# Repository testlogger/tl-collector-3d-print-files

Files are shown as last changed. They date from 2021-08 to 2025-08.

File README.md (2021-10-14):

# TestLogger Collector 3D printing file library
This repository is used to share STL files for TestLogger Collector components like cases and sensor brackets. As everything is 3D printed in production versions, we want to share the models for the users to be able to print spare parts by themselves and also users can share their own designs for brackets for others to print.

# Contributing
If you like to contribute your models to this library, then you can send models via email to info@testlogger.com or upload it in Discord.

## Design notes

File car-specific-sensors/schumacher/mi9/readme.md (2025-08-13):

# Schumacher Mi9 Brackets

This folder contains all brackets for the **Schumacher Mi9 touring car** and instructions for installation.

---

## 📑 Table of Contents
- [🧲 Magnet Ring](#-magnet-ring)
  - [Before You Start](#before-you-start)
  - [Installing the Magnet Ring](#installing-the-magnet-ring)
  - [Installing the Magnets](#installing-the-magnets)
- [⚙️ Wheel Speed Sensor Bracket](#️-wheel-speed-sensor-bracket)
- [💡 Tips & Notes](#-tips--notes)

---

## 🧲 Magnet Ring

The magnet ring has slots for **4 magnets**. The designed magnet size is **3×1 mm**.

### Before You Start
> ⚠️ **Important:** The ring is designed for **new or clean outdrives**. If you are using old outdrives, remove any extra material from the top surface before installation.

### Installing the Magnet Ring
1. Insert the **outer side** of the crescent-shaped pin into the driveshaft bearing slot on the diff outdrive.  
2. The ring should fit snugly.  
   💡 *You can secure it with a **tiny** drop of CA glue if needed.*

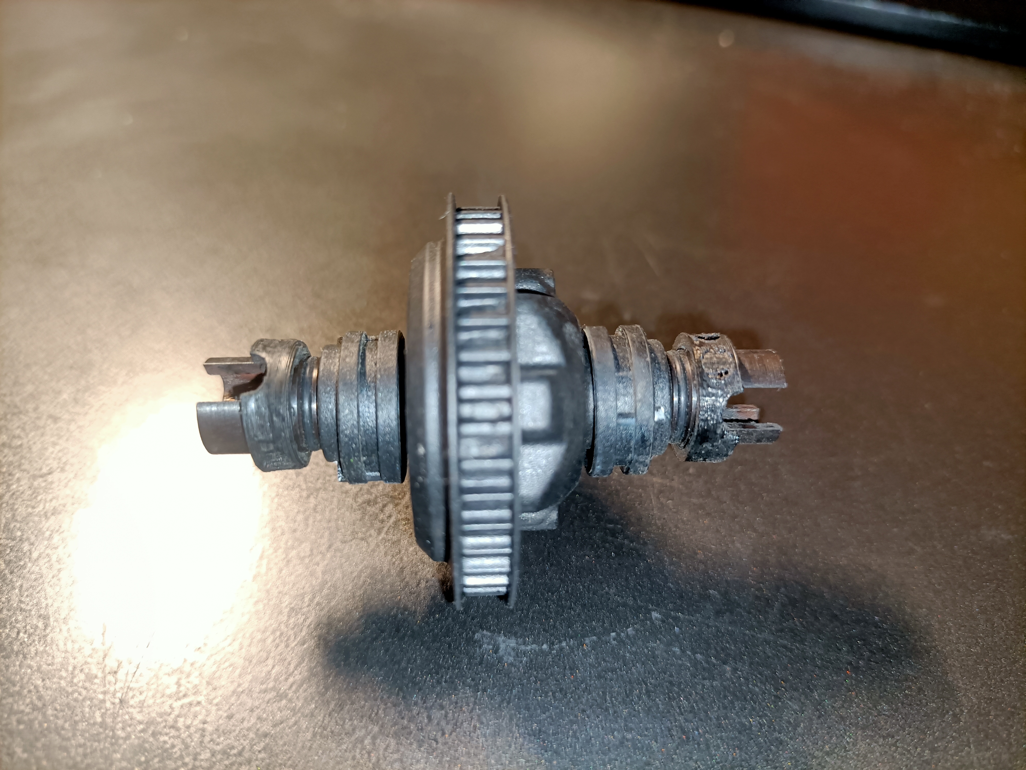
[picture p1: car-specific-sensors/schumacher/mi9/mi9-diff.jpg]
Magnet ring on diff outdrive


---

### Installing the Magnets

1. Use **long-nose pliers** or any pliers with a thin, flat tip.  
2. Apply a small piece of **packing tape** to the plier tips to avoid scratching the magnets.  
3. Open the magnet package without removing them from the sticker backing.  
   💡 *Tip: Place the sticker on a **metal surface** so magnets stay in place.*  
4. Pick up the first magnet using the pliers.  
5. Place the magnet into one of the slots on the magnet ring.  
   ⚠️ *Only use **non-through holes** — through holes are for balancing only.*  
6. Gently press the magnet into place with the pliers.  
7. Slide the pliers away from the magnet.  
8. Repeat for the remaining three magnets.  

---

## ⚙️ Wheel Speed Sensor Bracket

1. Select the bracket matching your **transmission housing** (kit or high trans housing).  
2. Remove the **differential**, unscrew the trans housing from the chassis plate, and insert the bracket pin into the corresponding hole.  

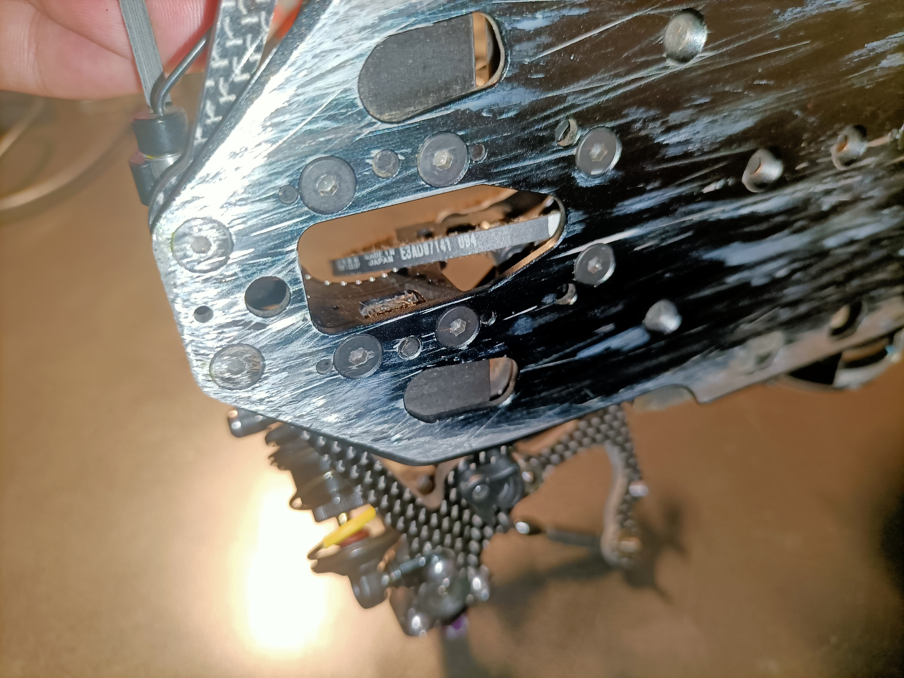
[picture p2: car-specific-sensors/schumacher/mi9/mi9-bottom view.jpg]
Bracket pin placement from bottom view
   

3. Place the trans housing over the bracket, ensuring the pin stays in place.  
4. Attach the sensor to the bracket using **double-sided tape**.  
   📏 *The sensor’s black square must face the magnet ring on the diff outdrive.*  

   Top view of sensor mounting

5. Once fully assembled, it should look like this:  

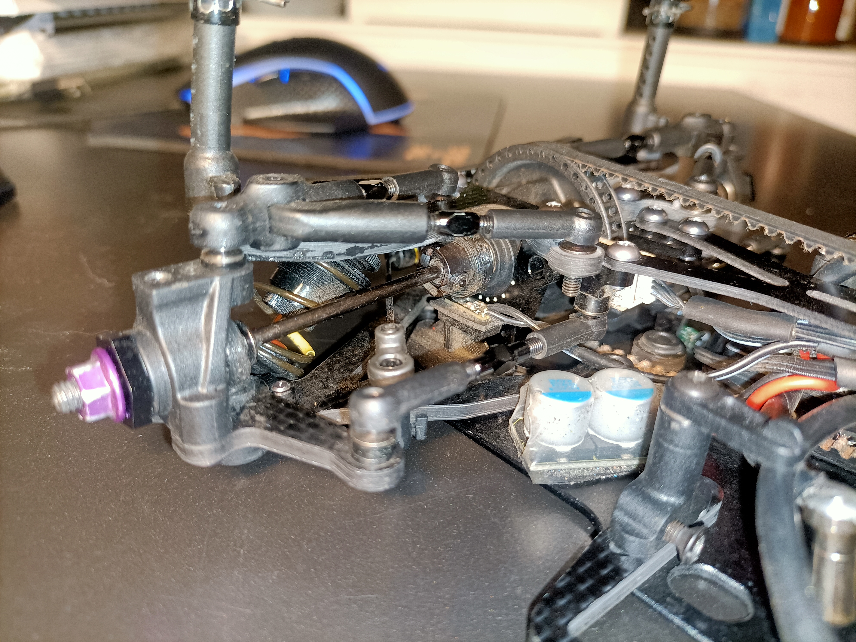
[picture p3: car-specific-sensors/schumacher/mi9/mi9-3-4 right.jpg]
3/4 right view
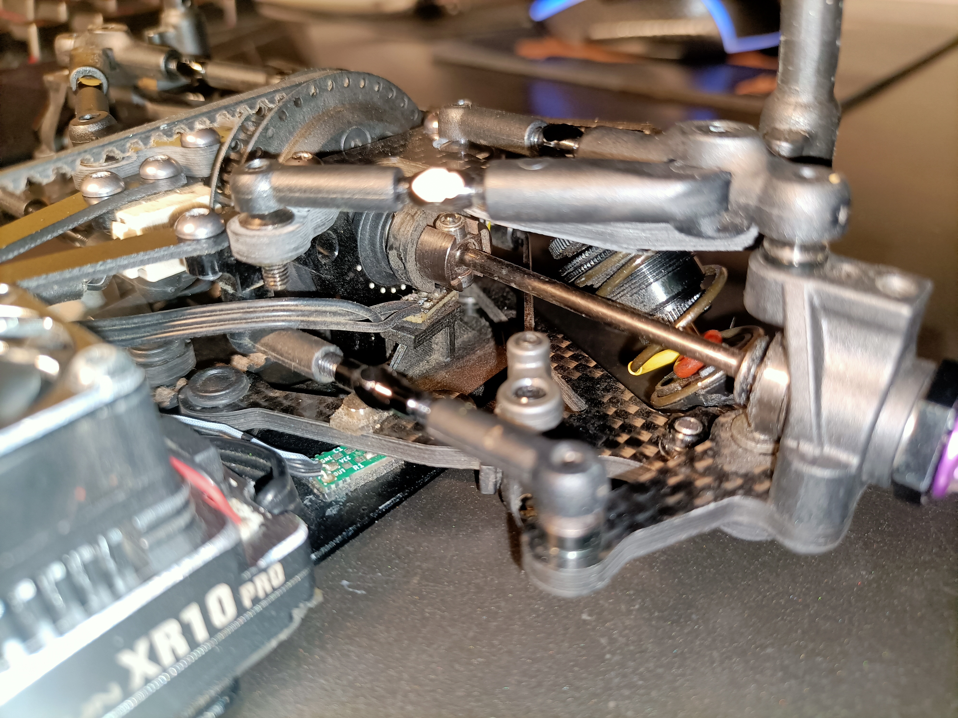
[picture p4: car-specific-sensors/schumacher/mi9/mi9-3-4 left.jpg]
3/4 left view
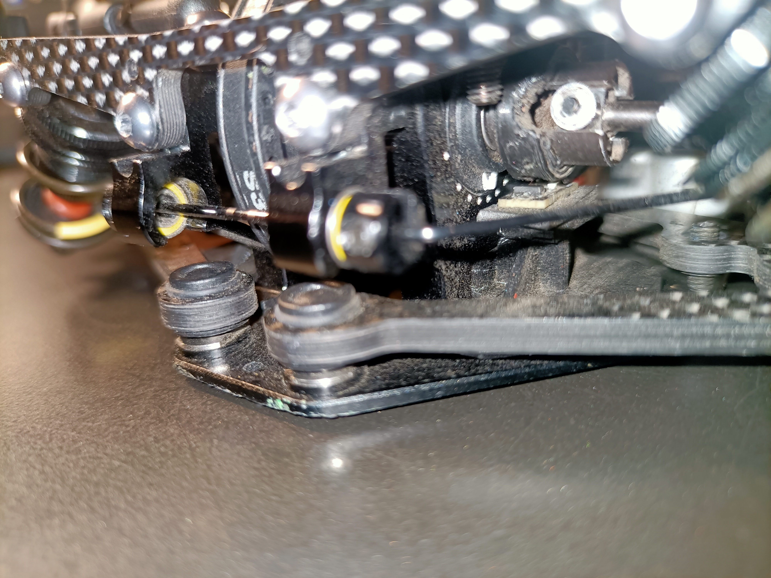
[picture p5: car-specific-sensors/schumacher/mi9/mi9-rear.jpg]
Rear view
     

---

## 💡 Tips & Notes

- 🕒 Take your time when installing magnets — a small misalignment can affect sensor readings.  
- 💧 If using CA glue, apply **only a minimal amount** to avoid damaging the ring.

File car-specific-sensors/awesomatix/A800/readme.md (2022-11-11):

# Awesomatix A800 series brackets
This folder has all brackets for Awesomatix A800 electric 4WD touring car. This file has some instructions and information about the brackets

## Magnet ring
Magnet ring has slot for four magnets. Designed magnet size is 3x1mm.
* Ring is designed to be installed to new outdrives, so make sure you clean any extra material from top level of outdrive if you use old outdrives.
* To install the ring, please push thinner part of the ring against outdrive o-ring. Make sure it doesn't touch eccentric hub so the magnet ring doesn't generate additional friction.
* Ring should fit in place quite nicely but it is ok to secure the installation with small amount of CA glue.

How install magnets?
1. Get long nose pliers or any pliers with fairly thin flat surface on the tip
2. Put piece of packing tape on the flat surface of the tip
3. Open the magnets in the sticker package. Keep magnets on top of the sticker and place sticker on table. Tip: Place the sticker on metal surface so magnets on top of the sticker will stay in place.
4. Take first magnet from the top with a tip of the pliers.
5. Put one drop of CA glue on flat edge of the magnet
6. Place magnet to one of the slots in magnet ring
7. Compress magnet to the slot gently with the pliers
8. Slide pliers off from the magnet
9. Repeat for other three magnets.

## Wheel speed sensor bracket
To be designed

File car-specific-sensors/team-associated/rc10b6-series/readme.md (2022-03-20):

# Team Associated B6 series brackets
This folder has all brackets for AE RC10B6 series two wheel drive car. This file has some instructions how to install the

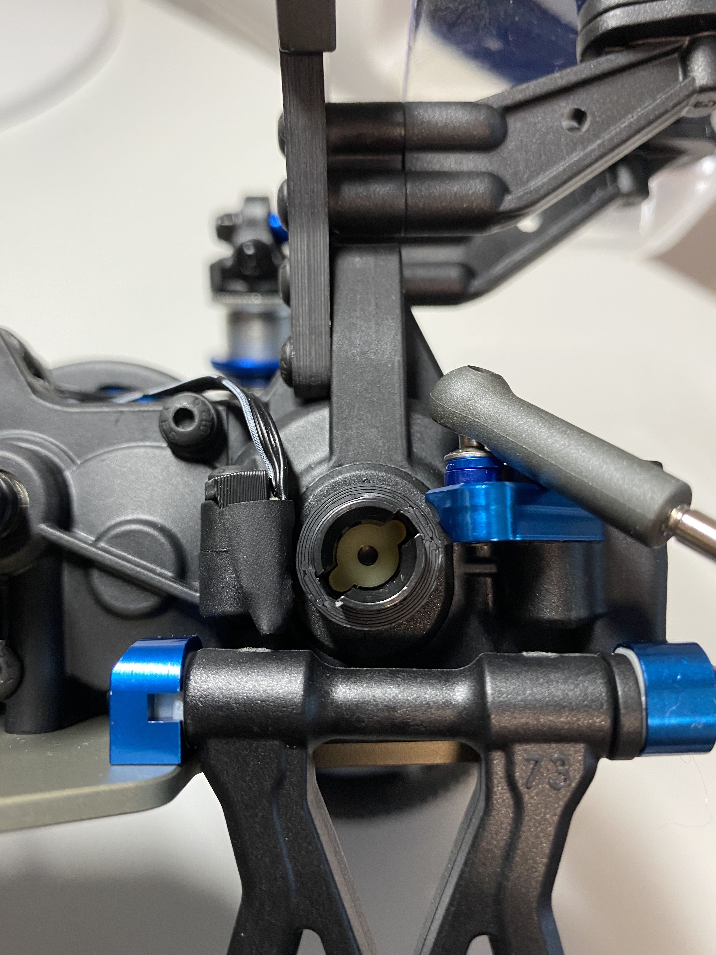
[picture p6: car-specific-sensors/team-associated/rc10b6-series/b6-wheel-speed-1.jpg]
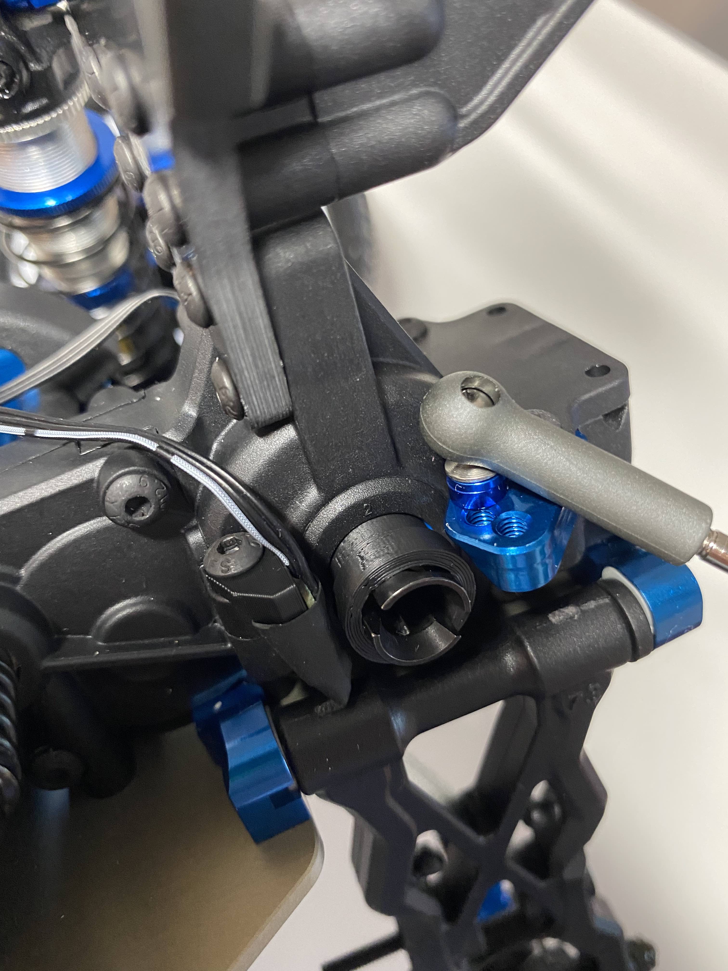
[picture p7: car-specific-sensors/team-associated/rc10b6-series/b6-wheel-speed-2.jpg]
 

## Magnet ring
Magnet ring has slot for four magnets. Designed magnet size is 3x1mm.
* Ring is designed to be installed to new outdrives, so make sure you clean any extra material from top level of outdrive if you use old outdrives.
* To install the ring, please push thinner part of the ring against outdrive bearings
* Ring should fit in place quite nicely but it is ok to secure the installation with small amount of CA glue.

How install magnets?
1. Get long nose pliers or any pliers with fairly thin flat surface on the tip
2. Put piece of packing tape on the flat surface of the tip
3. Open the magnets in the sticker package. Keep magnets on top of the sticker and place sticker on table. Tip: Place the sticker on metal surface so magnets on top of the sticker will stay in place.
4. Take first magnet from the top with a tip of the pliers.
5. Put one drop of CA glue on flat edge of the magnet
6. Place magnet to one of the slots in magnet ring
7. Compress magnet to the slot gently with the pliers
8. Slide pliers off from the magnet
9. Repeat for other three magnets.

## Wheel speed sensor bracket
* Fix sensor to the bracket with 6mm shrink tube which comes with the wheel speed sensor
* You can adjust the sensor height by using spacers below the bracket. This would be necessary if you adjust the diff height.

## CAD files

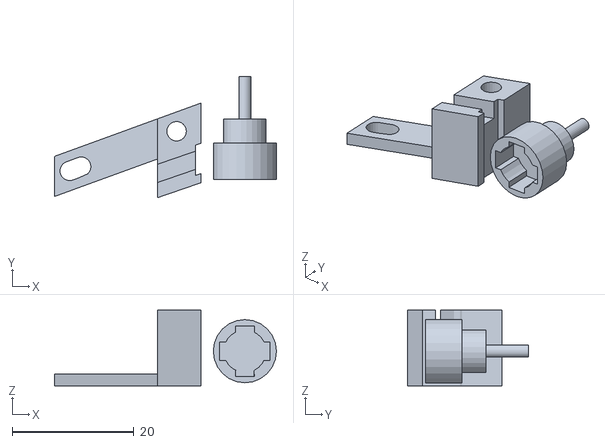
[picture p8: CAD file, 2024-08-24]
car-specific-sensors/awesomatix/A800/FWD-rearwheel-magnets+ sensor-holder.stl
36.5 x 20.0 x 12.5

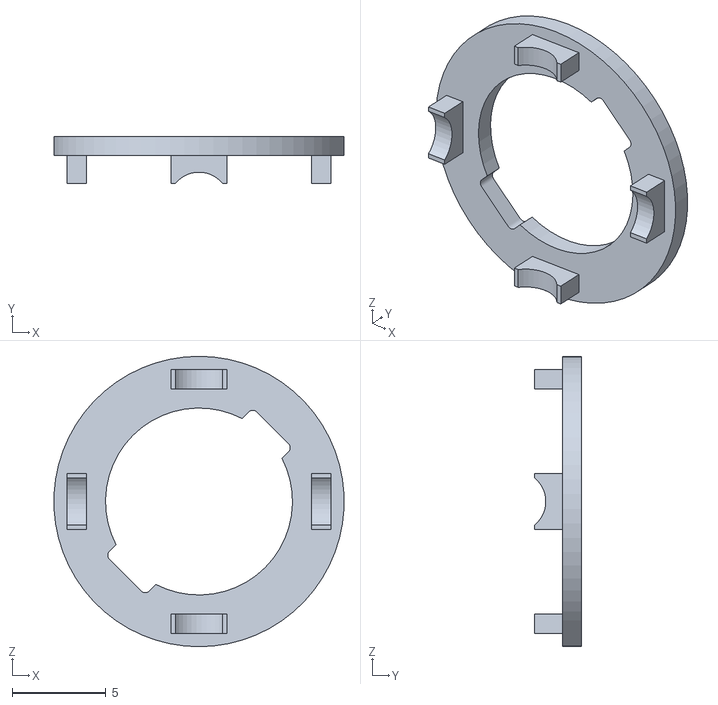
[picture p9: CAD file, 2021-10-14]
car-specific-sensors/shepherd/velox-v10/MagnetSupport/Magnet_Support_2_B.STL
15.5 x 2.50 x 15.5

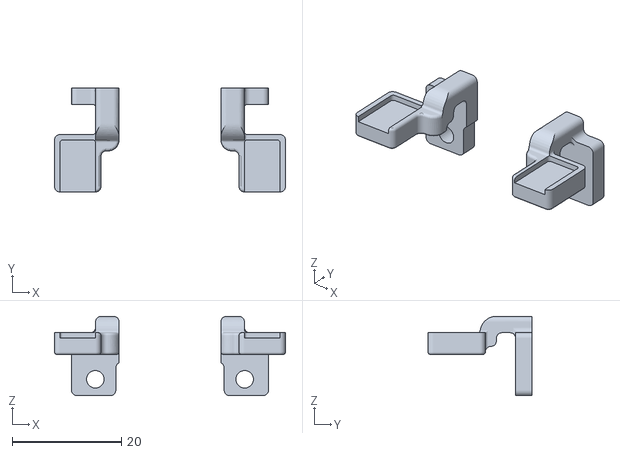
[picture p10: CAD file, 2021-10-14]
car-specific-sensors/shepherd/velox-v10/SpeedSensorSupport/WheelSpeedSensorSupport_C.STL
42.2 x 19.0 x 14.5

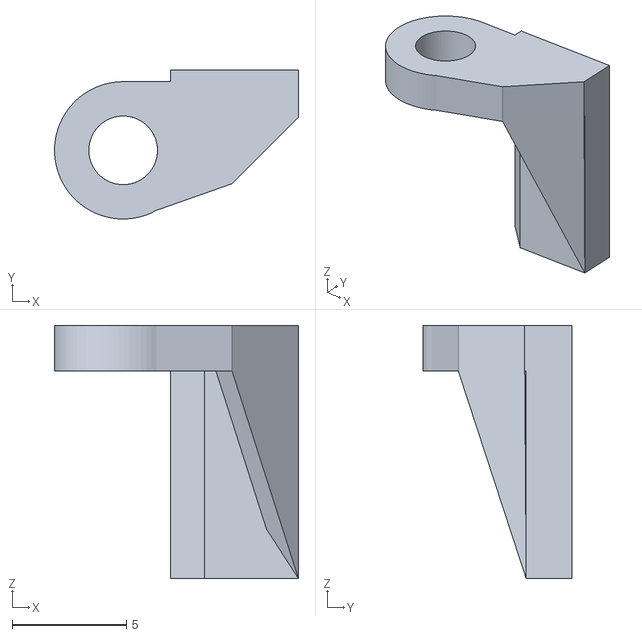
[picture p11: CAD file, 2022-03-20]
car-specific-sensors/team-associated/rc10b6-series/speed-sensor-bracket-lh.stl
10.7 x 6.51 x 11.1

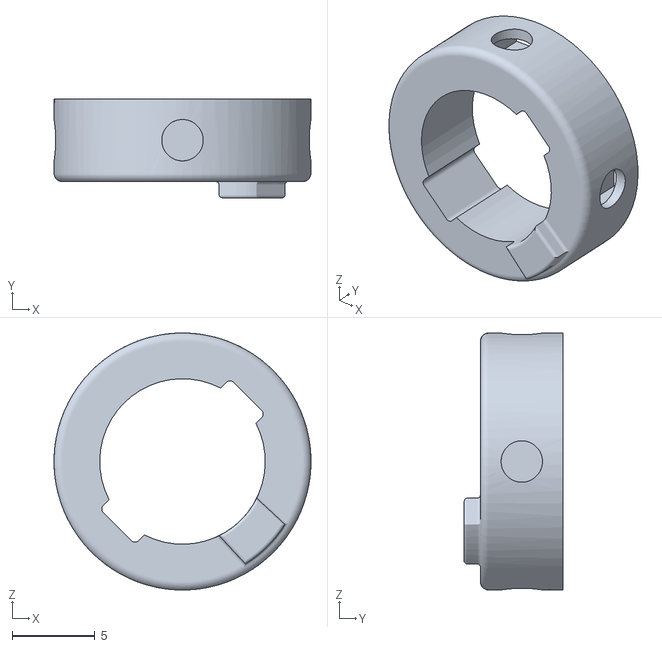
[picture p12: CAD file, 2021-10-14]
car-specific-sensors/shepherd/velox-v10/MagnetSupport/Magnet_Support_1_B.STL
15.5 x 6.00 x 15.5

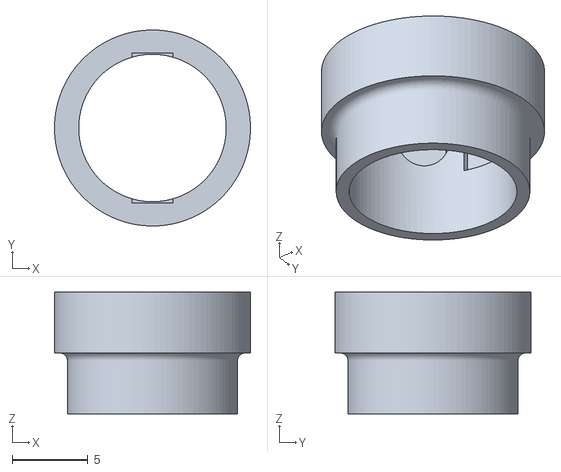
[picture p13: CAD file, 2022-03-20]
car-specific-sensors/team-associated/rc10b6-series/magnet-ring.stl
12.9 x 12.9 x 8.00

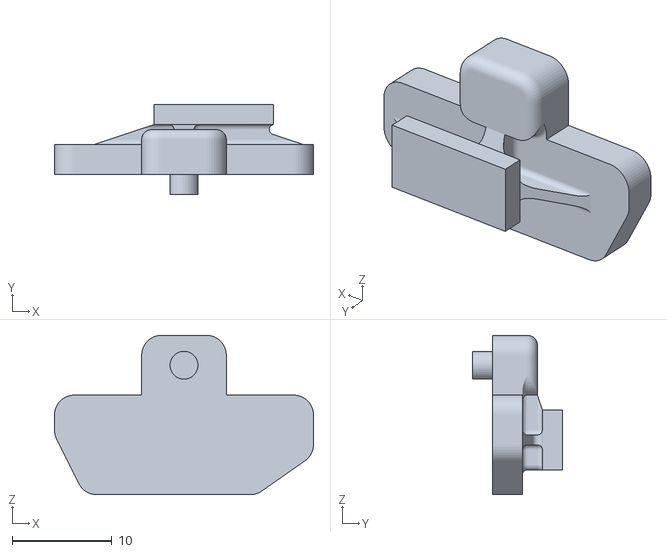
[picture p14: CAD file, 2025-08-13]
car-specific-sensors/schumacher/mi9/TL0312003 - Wlspd sensor_Left Bracket_Kit trans housing v3.stl
26.0 x 9.00 x 16.0

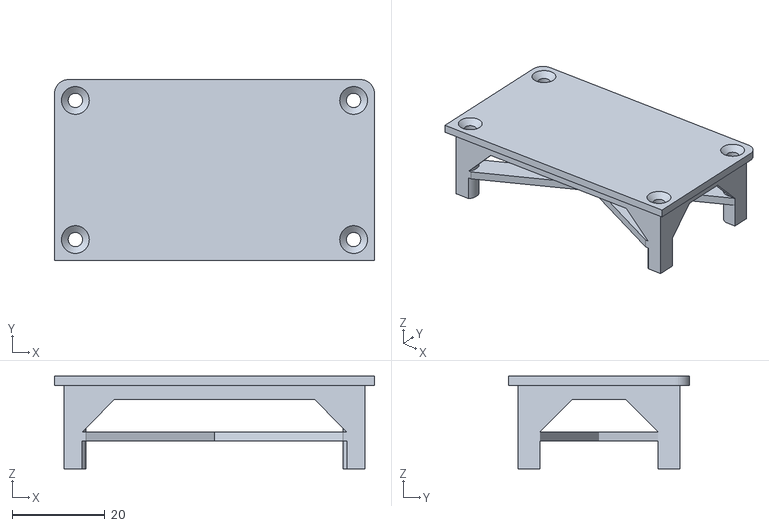
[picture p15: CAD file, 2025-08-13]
generic-sensors/TL0102001-collector-beacon/TL0202002-collector-beacon-cover.stl
69.0 x 39.0 x 20.0

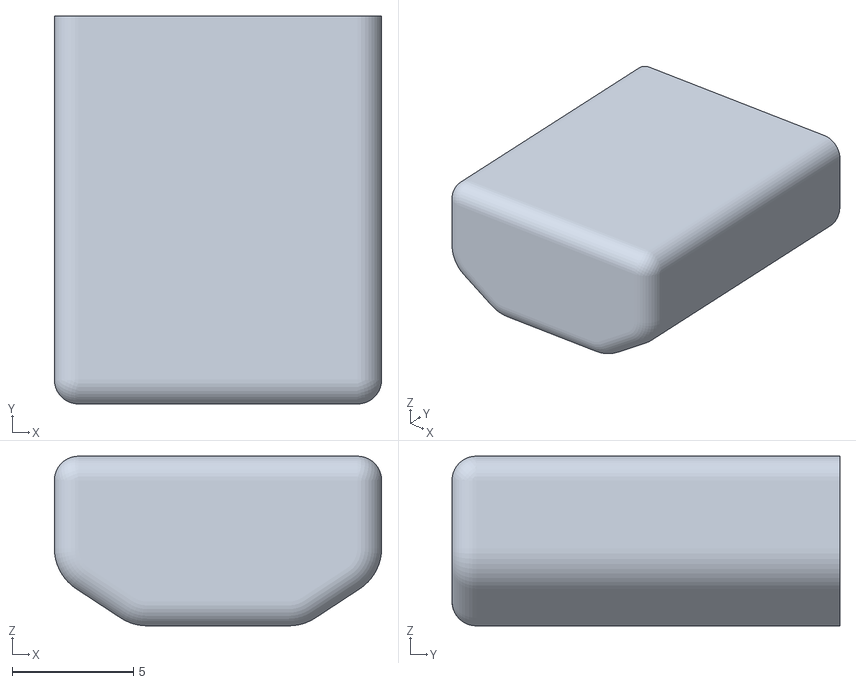
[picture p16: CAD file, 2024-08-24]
generic-sensors/TL0103006-lap-receiver/TL0103006-lap-receiver-cover.stl
13.5 x 16.0 x 7.00

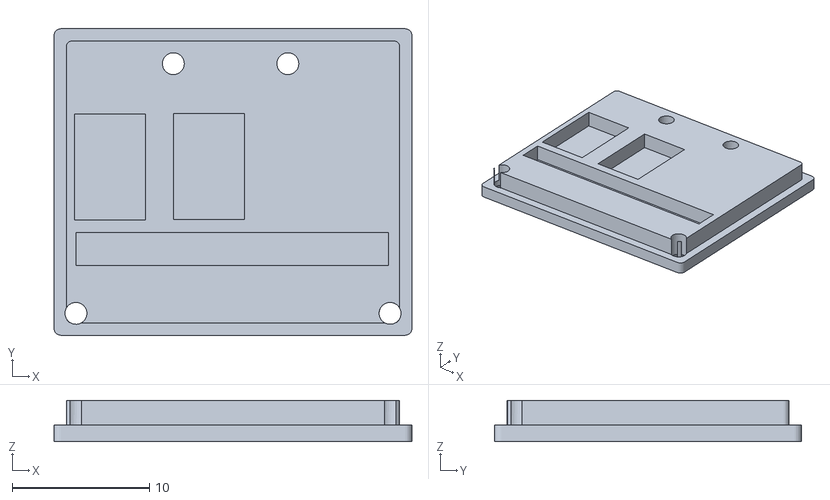
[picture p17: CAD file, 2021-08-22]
main-units/TL0101001-collector-mini/TL0201001-base.stl
26.1 x 22.4 x 3.00

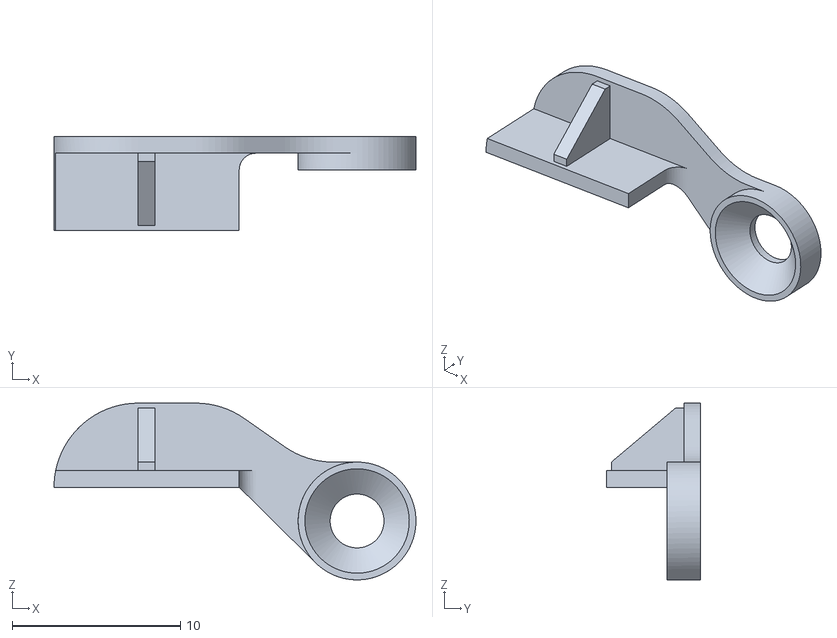
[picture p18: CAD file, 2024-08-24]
car-specific-sensors/awesomatix/A800/TL0306003 - Wlspd sensor_Left Bracket v3.stl
21.5 x 5.60 x 10.5

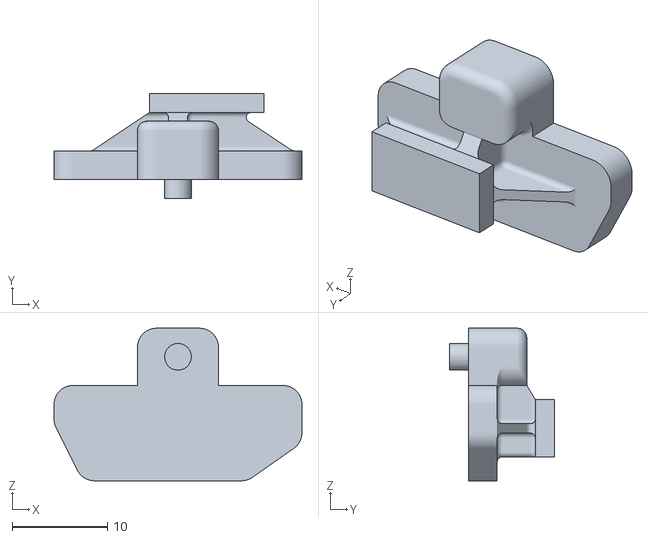
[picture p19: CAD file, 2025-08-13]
car-specific-sensors/schumacher/mi9/TL0312005 - Wlspd sensor_Left Bracket_+2mm trans housing v2.stl
26.0 x 11.0 x 16.0

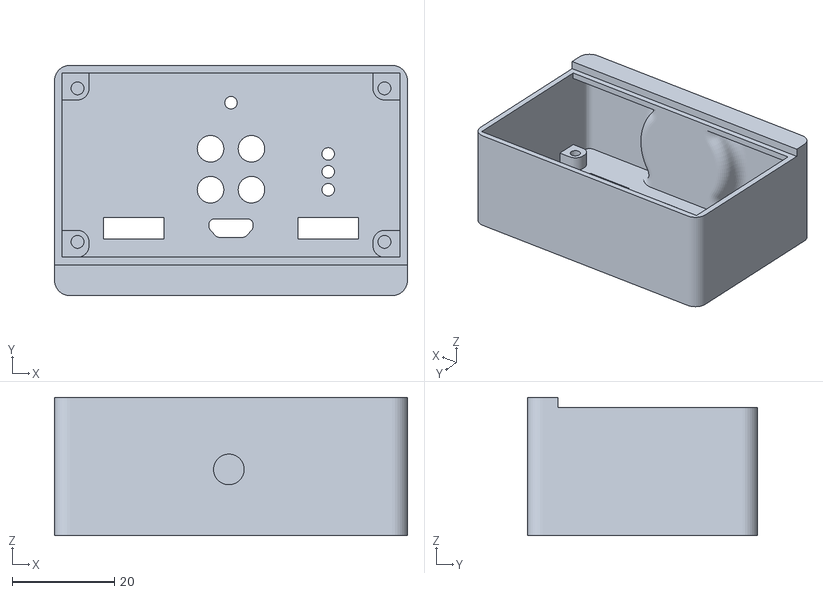
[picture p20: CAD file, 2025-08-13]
generic-sensors/TL0102001-collector-beacon/TL0202001-collector-beacon-housing.stl
69.0 x 45.0 x 27.0

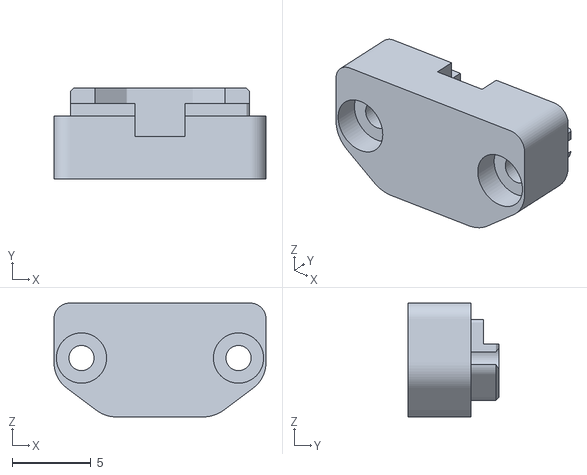
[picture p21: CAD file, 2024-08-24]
generic-sensors/TL0103006-lap-receiver/TL0103006-lap-receiver-base-low.stl
13.5 x 5.80 x 7.25

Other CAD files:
car-specific-sensors/team-associated/rc10b6-series/speed-sensor-bracket-rh.stl
main-units/TL0101001-collector-mini/TL0201002-case.stl
car-specific-sensors/awesomatix/A800/TL0306002 - Wlspd sensor_Right Bracket v9.stl
car-specific-sensors/schumacher/mi9/TL0312004 - Wlspd sensor_Right Bracket_+2mm trans housing v9.stl
car-specific-sensors/awesomatix/A800/TL0306001 - Magnet ring v8.stl
car-specific-sensors/schumacher/mi9/TL0312001 - Magnet ring v1.stl
car-specific-sensors/schumacher/mi9/TL0312002 - Wlspd sensor_Right Bracket_Kit trans housing v4.stl
generic-sensors/TL0102001-collector-beacon/TL0202003-collector-beacon-switch-cap.stl
generic-sensors/TL0103006-lap-receiver/TL0103006-lap-receiver-base-high.stl

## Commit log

2021-08-22 Collector Mini PR1 and Beacon PR1
    [TL0201001-collector-mini-pr1-base.stl, TL0201002-collector-mini-pr1-case.stl, TL0202001-collector-beacon-housing.stl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]
2021-10-14 Updated Readme and added Shepherd Velox V10 speed sensor brackets
    [Magnet_Support_1_B.STL, Magnet_Support_2_B.STL, WheelSpeedSensorSupport_C.STL]
2022-03-20 First version of B6 wheel speeds
    [magnet-ring.stl, speed-sensor-bracket-lh.stl, speed-sensor-bracket-rh.stl]
2022-11-11 Awesomatix A800 magnet ring
    [magnet-ring.stl]
2022-11-11 Collector Mini cases
    [TL0201001-base.stl, TL0201002-case.stl]
2022-11-11 Removed extra files
    [TL0201001-collector-mini-pr1-base.stl, TL0201002-collector-mini-pr1-case.stl]
2024-08-24 A800 speed sensor brackets and lap receiver casing added
    [TL0103006-lap-receiver-base-high.stl, TL0103006-lap-receiver-base-low.stl, TL0103006-lap-receiver-cover.stl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]
2024-08-24 Awesomatix A800 FWD speed sensor brackets added
    [FWD-rearwheel-magnets+ sensor-holder.stl]
2025-08-13 Schumacher Mi9 brackets
    [TL0312001 - Magnet ring v1.stl, TL0312002 - Wlspd sensor_Right Bracket_Kit trans housing v4.stl, TL0312003 - Wlspd sensor_Left Bracket_Kit trans housing v3.stl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]
2025-08-13 Beacon covers
    [TL0202001-collector-beacon-housing.stl, TL0202002-collector-beacon-cover.stl]
2025-08-13 Schumacher Mi9 bracket documentation
